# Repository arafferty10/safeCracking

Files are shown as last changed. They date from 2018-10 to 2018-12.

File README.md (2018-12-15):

# Team TAL: ATLS 4519 Safecracking Fall 2018
#### Repo for SafeCracking Class -- Using Arduino and manufactured parts to open a Sentry Safe Dial Safe

IMAGE ALT TEXT (http://www.youtube.com/watch?v=GAtKnZO2PP4 "ATLS 4519 Safe Cracking Success ")
###### Successful Opening Video

## Information

Parts List - https://docs.google.com/spreadsheets/d/1XabOUtS-7bFRwG6XeN5u8nKVINY24XkEVGik6j0RJdE/edit?usp=sharing  
3D Printed Models - https://github.com/arafferty10/safeCracking/tree/master/models

## Personal Repos
* Lou - https://github.com/lume2651/safe-cracking 
* Aidan - https://github.com/arafferty10/personalSafeCracking
* Toby - https://github.com/towu1344/Safe-Cracking

## Images
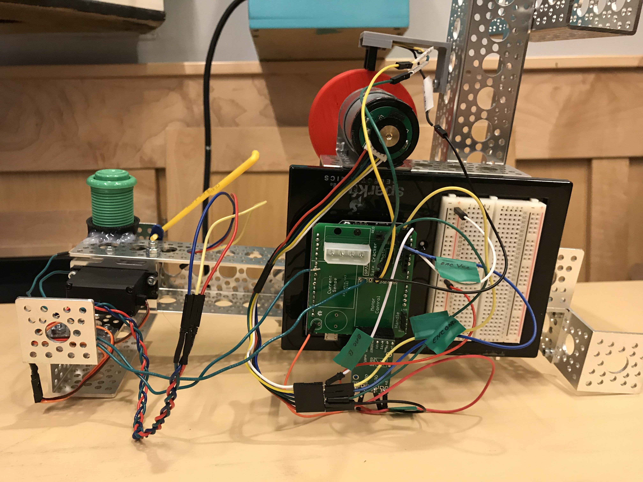
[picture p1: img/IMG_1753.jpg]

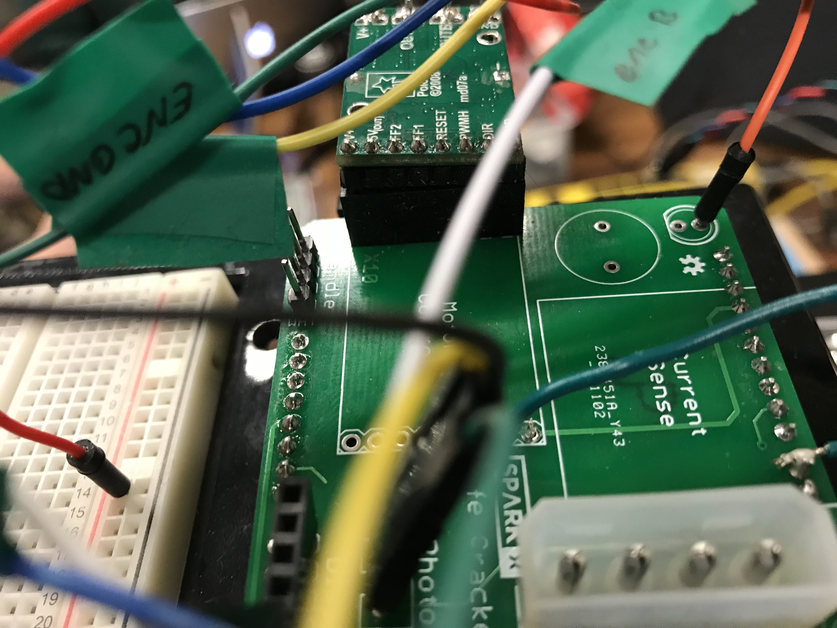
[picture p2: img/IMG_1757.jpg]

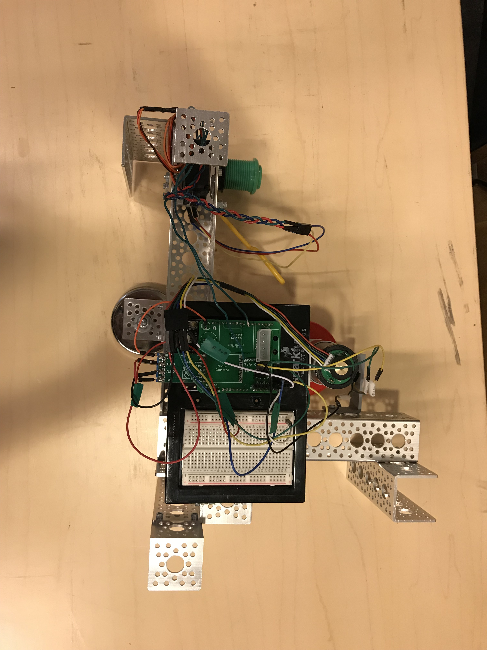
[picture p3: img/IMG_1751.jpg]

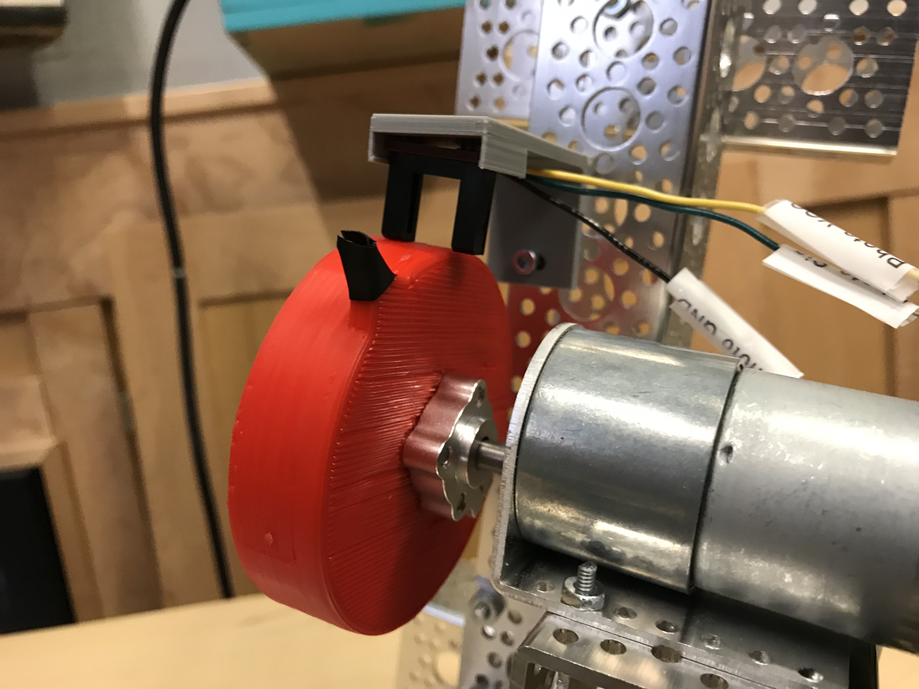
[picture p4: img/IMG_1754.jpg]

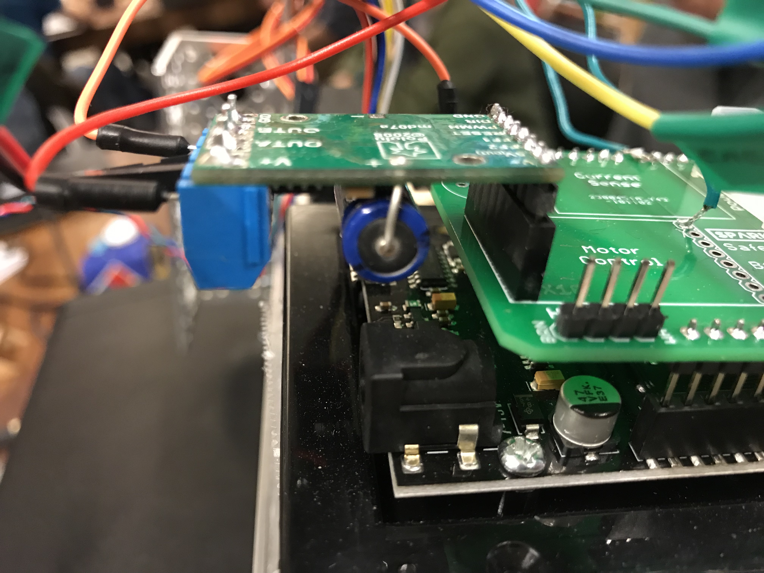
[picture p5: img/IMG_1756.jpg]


---
Video of final opening: https://github.com/arafferty10/safeCracking/blob/master/img/IMG_3121.mp4

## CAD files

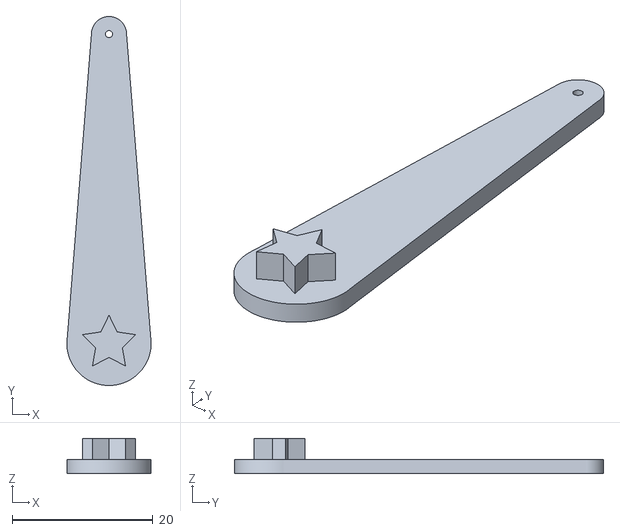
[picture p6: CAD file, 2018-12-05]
models/handlePullerArm.stl
12.0 x 52.5 x 5.00

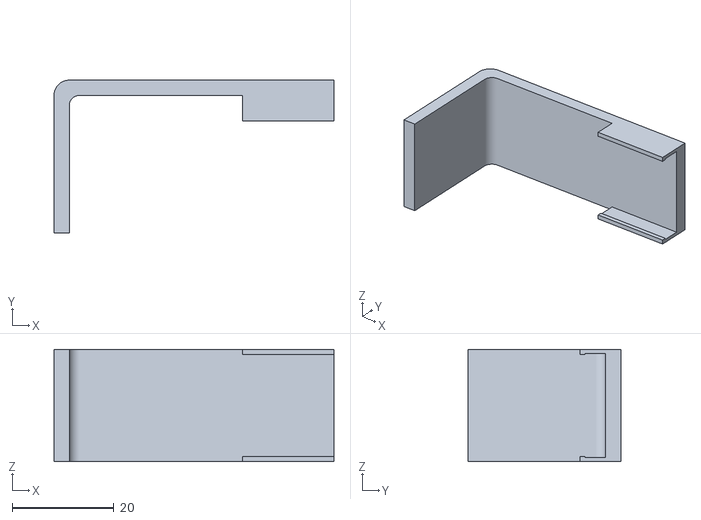
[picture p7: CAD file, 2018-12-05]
models/phoGateHolder.stl
55.0 x 30.0 x 22.0

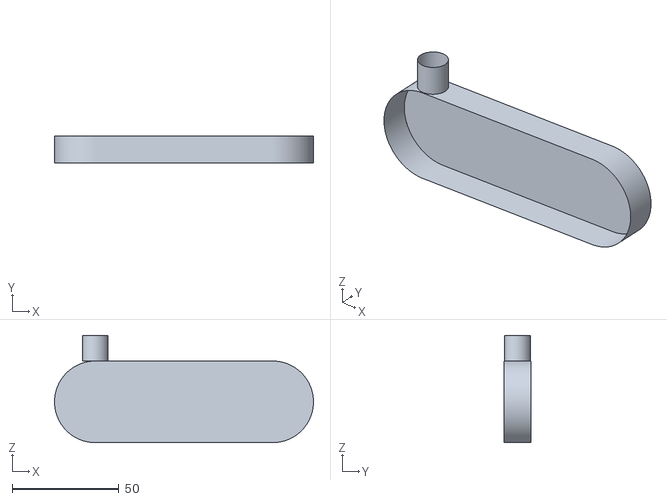
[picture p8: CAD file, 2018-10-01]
models/lou-handle-puller.stl
121.2 x 12.8 x 50.2

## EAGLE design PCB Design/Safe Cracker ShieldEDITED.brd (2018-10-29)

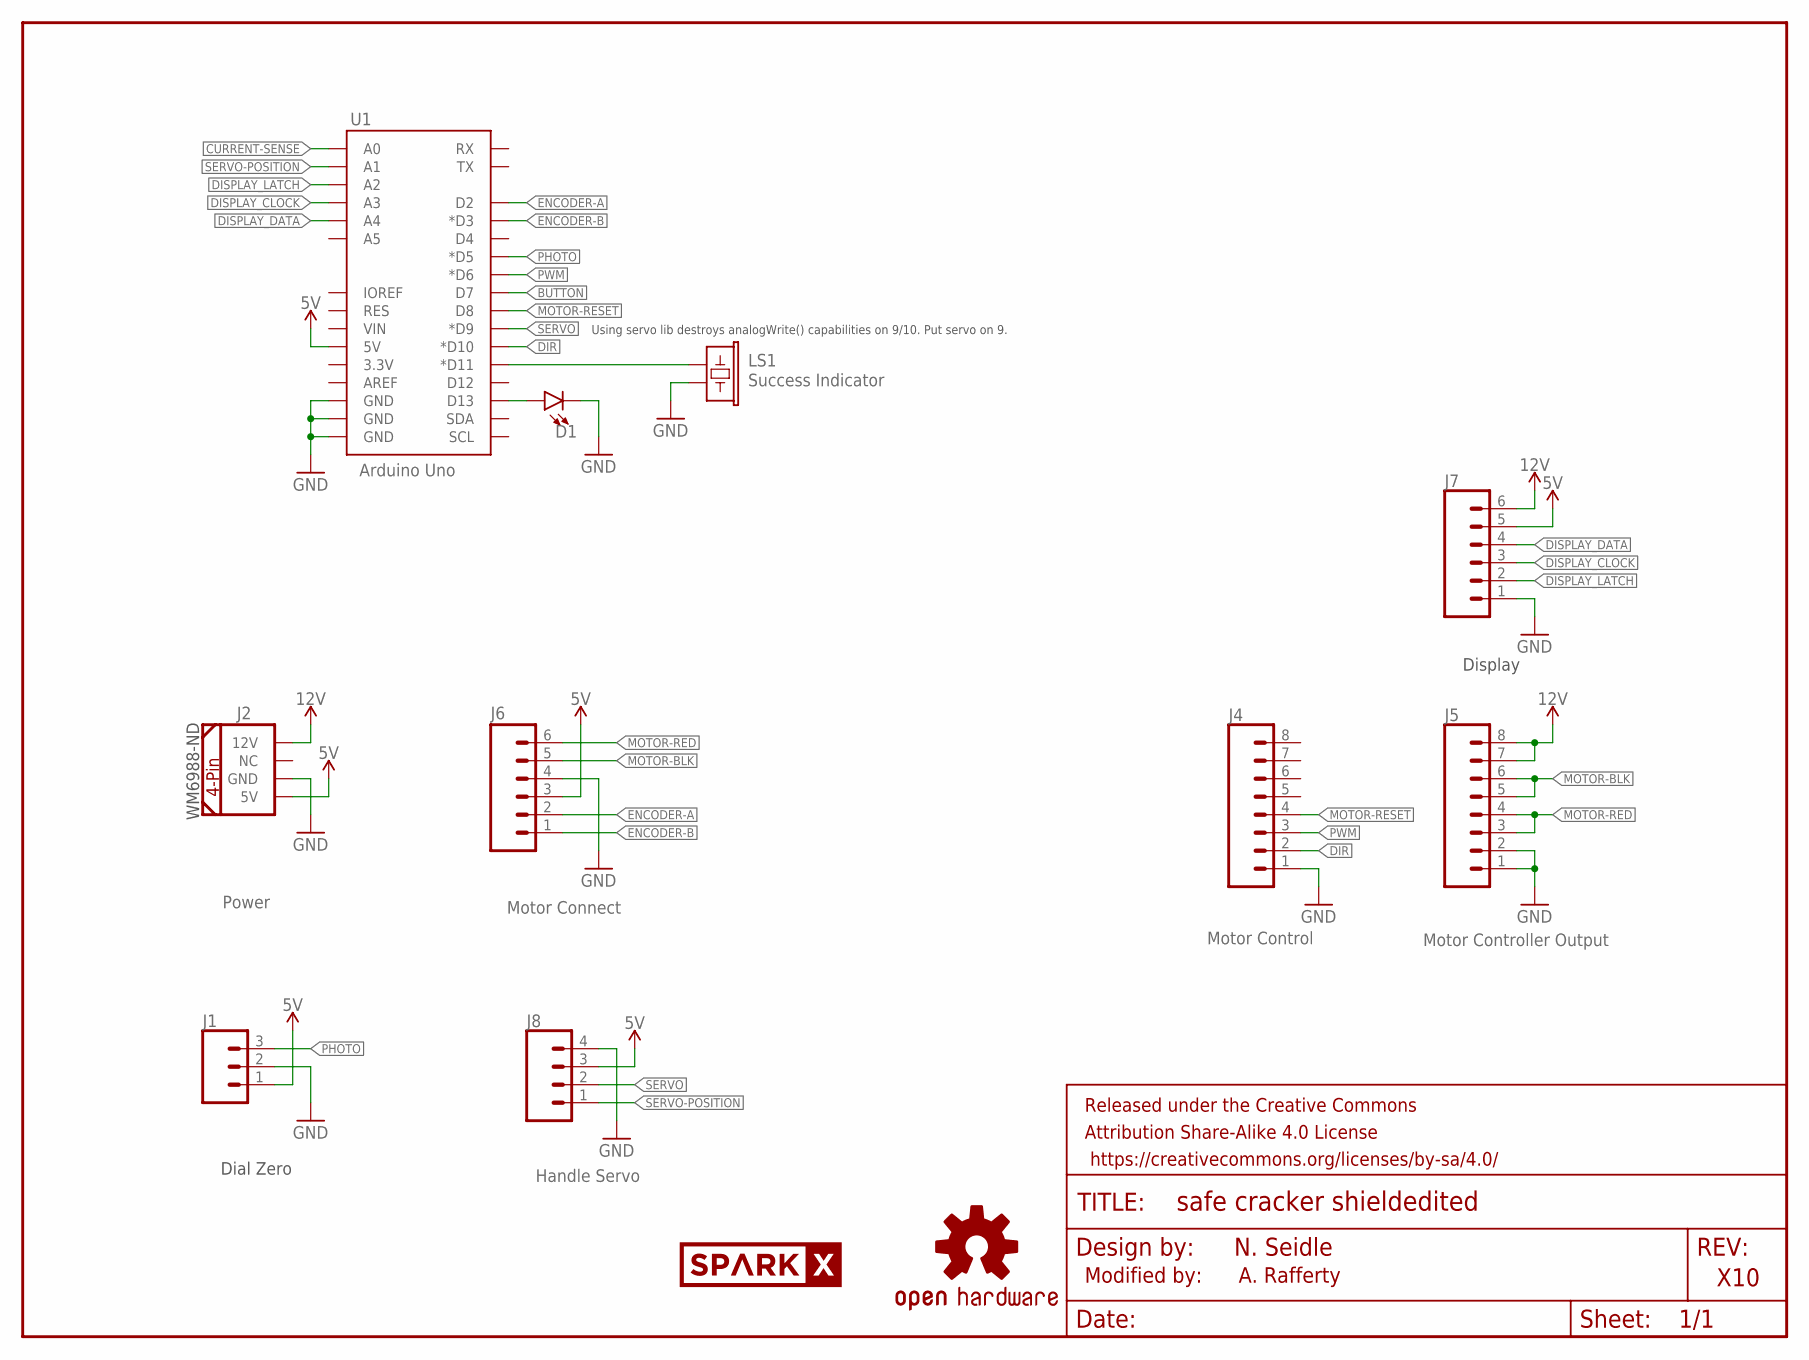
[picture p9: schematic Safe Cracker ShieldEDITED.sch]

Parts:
D1: LED5MM; LED_5MM
FRAME1: FRAME-LETTER; CREATIVE_COMMONS
J1: CONN_03JST-PTH-VERT; JST-3-PTH-VERT
J2: Power; COMPUTER-PERIPHERAL-POWER-RA
J4: Motor Control; 1X08
J5: Motor Controller Output; 1X08
J6: Motor Connect; 1X06@1
J7: CONN_06SILK_FEMALE_PTH; 1X06
J8: Handle Servo; 1X04
LOGO2: OSHW-LOGOS; OSHW-LOGO-S
LS1: Success Indicator; BUZZER-12MM
U1: Arduino Uno; UNO_R3_SHIELD_NOLABELS
U$1: SPARKX-LOGO5; SPARKX-LARGE

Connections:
5V: J1.1, J2.5V, J6.3, J7.5, J8.3, U1.5V
12V: J2.12V, J5.7, J5.8, J7.6
BUTTON: U1.D7
BUZZ: LS1.+ (1), U1.D11 (*D11)
CURRENT-SENSE: U1.A0
DIR: J4.2, U1.D10 (*D10)
DISPLAY_CLOCK: J7.3, U1.A3
DISPLAY_DATA: J7.4, U1.A4
DISPLAY_LATCH: J7.2, U1.A2
ENCODER-A: J6.2, U1.D2
ENCODER-B: J6.1, U1.D3 (*D3)
GND: D1.K (C), J1.2, J2.GND, J4.1, J5.1, J5.2, J6.4, J7.1, J8.4, LS1.- (2), U1.GND@0 (GND), U1.GND@1 (GND), U1.GND@2 (GND)
MOTOR-BLK: J5.5, J5.6, J6.5
MOTOR-RED: J5.3, J5.4, J6.6
MOTOR-RESET: J4.4, U1.D8
unnamed: D1.A, U1.D13
PHOTO: J1.3, U1.D5 (*D5)
PWM: J4.3, U1.D6 (*D6)
SERVO: J8.2, U1.D9 (*D9)
SERVO-POSITION: J8.1, U1.A1

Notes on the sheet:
WM6988-ND
N. Seidle
X10
Using servo lib destroys analogWrite() capabilities on 9/10. Put servo on 9.
Dial Zero
Display
Modified by: A. Rafferty

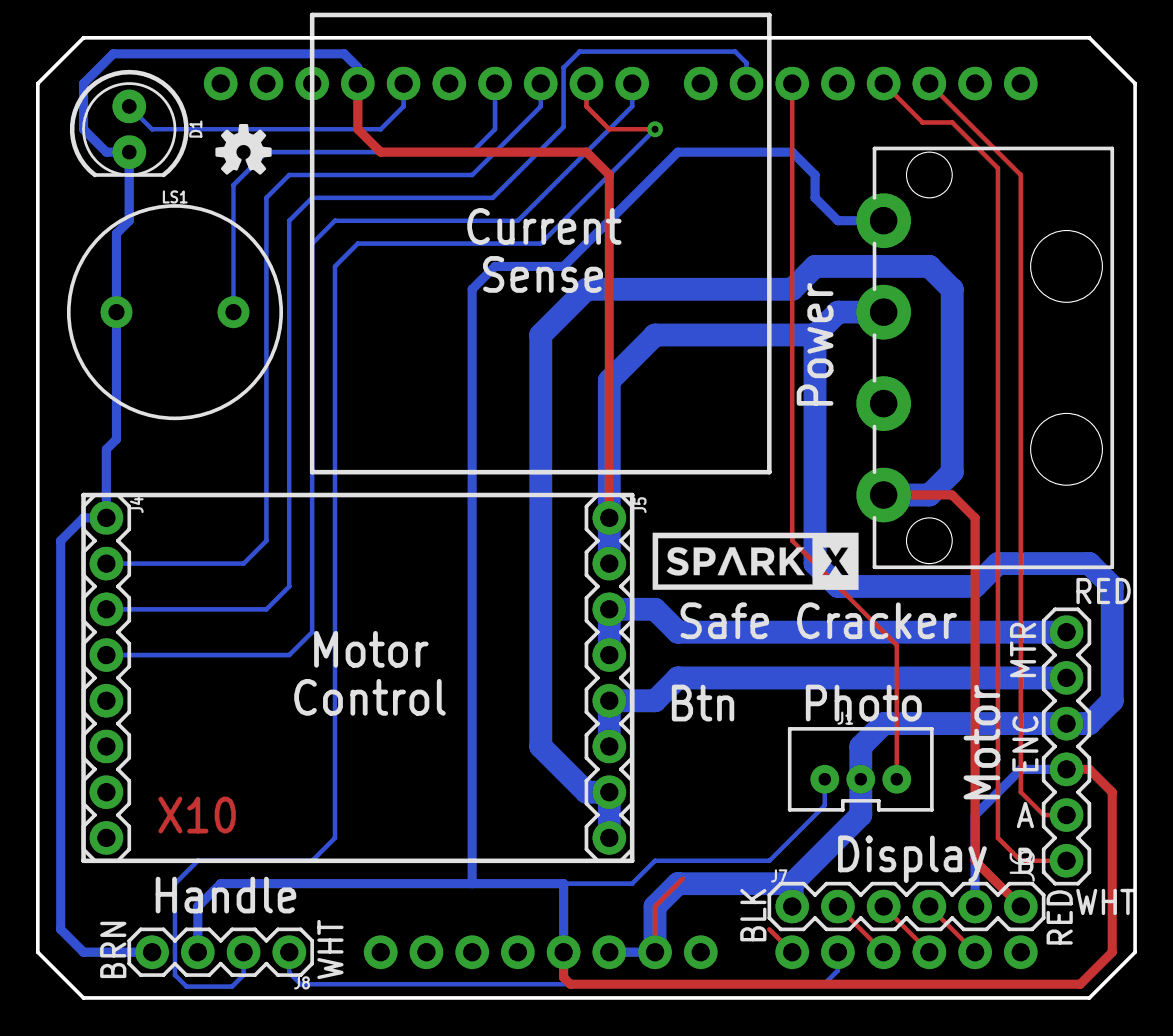
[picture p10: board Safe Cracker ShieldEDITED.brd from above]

Board: 2 copper layers, 61.0 x 53.3 mm, 13 parts (0 on the bottom side), 18 nets.

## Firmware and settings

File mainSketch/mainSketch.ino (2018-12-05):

#include <EEPROM.h>
#include <Servo.h>

#define CCW 0
#define CW 1
// EEPROM Storage Locations
const int DIAL_ROTATION_SPEED = 0;

#define LOCATION_HOME_OFFSET 0

// Pin layout
const int motorControl = 6;
const int photo = 7;
const int motorReset = 8;
const int motorDir = 3;

volatile int steps = 0;
boolean dir = CW;
boolean prevDir = CW;

byte homeOffset = 0;

const int timeMotorStop = 125;

int switchDirectionAdjustment = (84 * 0) + 0; //Use 'Test dial control' to determine adjustment size

//Rotate the dial Counter Clockwise
//-----------------------------------------------------
void rotateCCW(int _steps){
  Serial.println("inside rotateCCW()");

  digitalWrite(motorDir, LOW);

  int stepsLeft = _steps;

  while(stepsLeft > 0){
    Serial.println("trying to turn...");
    analogWrite(motorControl, 255);
    stepsLeft--;
  }
  analogWrite(motorControl, 0);
}
//-----------------------------------------------------

//Looks at current dial position and determines number of steps between where
//you are and where you want to go
//-----------------------------------------------------
int stepsRequired(int curSteps, int dest){
  if(dir == CW){
    if( curSteps >= dest) {
      return (curSteps - dest);
    } else if(curSteps < dest){
      return (8400 - dest + curSteps);
    }
  } else if(dir == CCW){
    if(curSteps >= dest){
      return (8400 - curSteps + dest);
    } else if(curSteps < dest){
      return (dest - curSteps);
    }
  }
}
//-----------------------------------------------------

//Given a step value, go to that step
//Returns the delta from what you asked and where it ended up
//Adding a full rotation will add a 360 degree full rotation
int gotoStep(int stepGoal, boolean addAFullRotation)
{
  //Coarse speed and window control how fast we arrive at the digit on the dial
  //Having too small of a window or too fast of an attack will make the dial
  //overshoot.
  int coarseSpeed = 200; //Speed at which we get to coarse window (0-255). 150, 200 works. 210, 230 fails
  int coarseWindow = 1250; //Once we are within this amount, switch to fine adjustment
  int fineSpeed = 50; //Less than 50 may not have enough torque
  int fineWindow = 32; //One we are within this amount, stop searching

  //Because we're switching directions we need to add extra steps to take
  //up the slack in the encoder
  if (dir == CW && prevDir == CCW)
  {
    steps += switchDirectionAdjustment;
    if (steps > 8400) steps -= 8400;
    prevDir = CW;
  }
  else if (dir == CCW && prevDir == CW)
  {
    steps -= switchDirectionAdjustment;
    if (steps < 0) steps += 8400;
    prevDir = CCW;
  }

  setMotorSpeed(coarseSpeed); //Go!
  while (stepsRequired(steps, stepGoal) > coarseWindow) ; //Spin until coarse window is closed

  //After we have gotten close to the first coarse window, proceed past the goal, then proceed to the goal
  if (addAFullRotation == true)
  {
    int tempStepGoal = steps + 8400/2; //Move 50 away from current position
    if (tempStepGoal > 8400) tempStepGoal -= 8400;

    //Go to temp position
    while (stepsRequired(steps, tempStepGoal) > coarseWindow) ;

    //Go to stepGoal
    while (stepsRequired(steps, stepGoal) > coarseWindow) ; //Spin until coarse window is closed
  }

  setMotorSpeed(fineSpeed); //Slowly approach

  while (stepsRequired(steps, stepGoal) > fineWindow) ; //Spin until fine window is closed

  setMotorSpeed(0); //Stop

  delay(timeMotorStop); //Wait for motor to stop

  int delta = steps - stepGoal;

  /*if (direction == CW) Serial.print("CW ");
    else Serial.print("CCW ");
    Serial.print("stepGoal: ");
    Serial.print(stepGoal);
    Serial.print(" / Final steps: ");
    Serial.print(steps);
    Serial.print(" / delta: ");
    Serial.print(delta);
    Serial.println();*/

  return (delta);
}

//-----------------------------------------------------

void enableMotor(){
  digitalWrite(motorReset, HIGH);
}

void disableMotor(){
  digitalWrite(motorReset, LOW);
}

// Sets rotation speed of dial motor
// Expects value between 0-100%
//-----------------------------------------------------
int setDialSpeed(int _rotationSpeed) {
  int rotSpeed = map(_rotationSpeed, 0, 100, 0, 255);
  EEPROM.put(rotSpeed, DIAL_ROTATION_SPEED);
  analogWrite(motorControl, rotSpeed);
  Serial.print(F("Dial speed set to: "));
  Serial.println(rotSpeed);

  return _rotationSpeed;
}
//-----------------------------------------------------

//Simple boolean to see if flag is detected
//-----------------------------------------------------
bool detectFlag(){

  if(digitalRead(photo) == LOW) {
    Serial.println("FLAG DETECTED");
    return (true);
  }
  return (false);

}
//-----------------------------------------------------

bool phoneHome(){

  // return atHome;
}

//Given a dial number, goto that value
//Returns the dial value thats ended on
//-----------------------------------------------------
int setDial(int dialValue, boolean extraSpin)
{
  //Serial.print("Want dialValue: ");
  //Serial.println(dialValue);

  int encoderValue = convertDialToEncoder(dialValue); //Get encoder value
  Serial.print("Want encoderValue: ");
  Serial.println(encoderValue);

  gotoStep(encoderValue, extraSpin); //Goto that encoder value
  Serial.print("After movement, steps: ");
  Serial.println(steps);

  int actualDialValue = convertEncoderToDial(steps); //Convert back to dial values
  Serial.print("After movement, dialvalue: ");
  Serial.println(actualDialValue);

  return (actualDialValue);
}

//-----------------------------------------------------

void setMotorSpeed(int speedValue)
{
  analogWrite(motorControl, speedValue);
}

//-----------------------------------------------------

//Given an encoder value, tell me where on the dial that equates
//Returns 0 to 99
//If there are 100 numbers on the dial, each number is 84 ticks wide
//-----------------------------------------------------
int convertEncoderToDial(int encoderValue)
{
  int dialValue = encoderValue / 84; //2388/84 = 28.43
  int partial = encoderValue % 84; //2388%84 = 36

  if (partial >= (84 / 2)) dialValue++; //36 < 42, so 28 is our final answer

  if (dialValue > 99) dialValue -= 100;

  return (dialValue);
}

//-----------------------------------------------------


//Given a dial value, covert to an encoder value (0 to 8400)
//If there are 100 numbers on the dial, each number is 84 ticks wide
//-----------------------------------------------------
int convertDialToEncoder(int dialValue)
{
  int encoderValue = dialValue * 84;

  if (encoderValue > 8400)
  {
    Serial.print("Whoa! Your trying to go to a dial value that is illegal. encoderValue: ");
    Serial.println(encoderValue);
    while (1);
  }

  return (84 * dialValue);
}

//-----------------------------------------------------

void setup() {

  pinMode(photo, INPUT_PULLUP);
  pinMode(motorDir, OUTPUT);
  pinMode(motorControl, OUTPUT);    //motorPWM
  pinMode(motorReset, OUTPUT);

  enableMotor();
  Serial.begin(115200);
  Serial.println();
  Serial.println("Safe Cracker");

  //Load settings from EEPROM
   homeOffset = EEPROM.read(LOCATION_HOME_OFFSET);

}

//-----------------------------------------------------
void loop() {

  char incoming;

  // Print text menu
  Serial.println();
  Serial.println("Main Menu");
  Serial.println(F("1. Rotate motor"));
  Serial.println(F("2. Detech Flag"));
  Serial.println(F("3. Set Starting Dial Value/Go Home"));
  Serial.println(F("4. placeholder option"));
  Serial.println(F("5. placeholder option"));
  Serial.println(F("6. Start Cracking!"));
  Serial.println();
  Serial.println(F("Enter your choice"));

  while(!Serial.available());


  incoming = Serial.read();

  // while(!Serial.available()){
    if(incoming == '1')
    {
      Serial.println("Case 1!");
      Serial.print("Rotating...");
      rotateCCW(1000);
    }
    else if(incoming == '2')
    {
      detectFlag();
      Serial.println("Case 2!");
    }
    //-----------------------------------------------------
    else if(incoming == '3')
    {
      Serial.println("Case 3!");
      //Go to starting conditions
      detectFlag(); //Detect the flag and center the dial based on it

      Serial.print(F("Offset from home is: "));
      Serial.println(homeOffset);

      int zeroLocation = 0;

      while (1) //Error checking
      {
        Serial.print(F("Enter where dial is actually at: "));

        while (!Serial.available()); //Wait for user input

        Serial.setTimeout(1000);
        zeroLocation = Serial.parseInt(); //Read user input

        Serial.print(zeroLocation);

        //Check to make sure the user input is in bounds
        if (zeroLocation >= 0 && zeroLocation <= 99) break;
        Serial.println(F(" out of bounds"));
      }

      homeOffset = zeroLocation;

      Serial.print(F("\n\rSetting home offset to: "));
      Serial.println(homeOffset);

      EEPROM.write(LOCATION_HOME_OFFSET, homeOffset);

      //Adjust steps with the real-world offset
      steps = (84 * homeOffset); //84 * the number the dial sits on when 'home'

      setDial(0, false); //Turn to zero

      Serial.println(F("Dial should be at: 0"));

    }
    //-----------------------------------------------------
    else if(incoming == '4')
    {
      Serial.println("Case 4!");
    }
    else
    {
      Serial.print("Unknown Option: ");
      Serial.println(incoming, HEX);
    }

  // }

  // while(!Serial.available()){
  //
  //   while(Serial.available());
  //   incoming = Serial.read();
  //   Serial.print("Incoming serial: ");
  //   Serial.println(incoming);
  //
  // }

}

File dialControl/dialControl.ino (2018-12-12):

#include <EEPROM.h>
#include <Servo.h>
#include "eeprom_loc.h"

Servo handle;

#define CCW 0
#define CW 1

// Pin definitions
const int motorControl = 6; // motor PWM
const int photoGate = 5;
const int motorReset = 8; // motor reset pin
const int motorDir = 10; // motor direction | HIGH - CW, LOW - CCW
const int encA = 2;
const int encB = 3;
const int servoPin = 9;

int testSpots[] = {99, 8, 16, 24, 33, 41, 50, 58, 66, 74, 83, 91}; 
boolean indentsToTry[12];
int indentWidths[12];
int indentLocations[12];


volatile int steps = 0;

boolean dir = CW; // default direction (also direction for first digit of combo)
boolean prevDir = CW;
int homeOffset = 0; // Found running findFlag()

int switchDirAdjustment = (84 * 0) + 0;

const int timeMotorStop = 125; // ms for motor to stop spinning after stop command

int servoRestingPosition = 0; // handle, at rest position
int servoTryPosition = 50; // position when measuring
int servoHighPressurePosition = 60; // position when opening safe

const int timeServoApply = 350;
const int timeServoRelease = 250;

void setup() {
  // put your setup code here, to run once:
  pinMode(photoGate, INPUT);
  pinMode(motorDir, OUTPUT);
  pinMode(motorControl, OUTPUT);
  pinMode(motorReset, OUTPUT);
//  handle.attach(servoPin);
//  handle.write(0);
  motorOn();
  Serial.begin(115200);
  Serial.println();
  Serial.println("Safe Cracker");

  attachInterrupt(digitalPinToInterrupt(encA), countA, CHANGE);
  attachInterrupt(digitalPinToInterrupt(encB), countB, CHANGE);

  // Load settings from EEPROM
  EEPROM.get(LOCATION_HOME_OFFSET, homeOffset); // read in homeOffset
  Serial.print("Home offset: ");
  Serial.println(homeOffset);

  // Init dial -> find home, set offset, go to zero
//  findFlag();
//  steps = (84 * homeOffset);
//  setDial(0, false);
  
}

void loop() {

  char incoming;

  // Print text menu
  Serial.println();
  Serial.println("Main Menu");
  Serial.println(F("1. Go home | Reset Dial"));
  Serial.println(F("2. Go to specific dial number"));
  Serial.println(F("3. Dial position testing"));
  Serial.println(F("4. Measure indents"));
  Serial.println(F("5. Position Testing"));
  Serial.println(F("6. Display Indent Center Values"));
  Serial.println(F("7. Test servo"));
  Serial.println();
  Serial.println(F("Enter your choice"));

  while(!Serial.available());


  incoming = Serial.read();

  // while(!Serial.available()){
    if(incoming == '1')
    {
      findFlag();
      Serial.print("Home offset: ");
      Serial.println(homeOffset);

      int zeroLocation = 0;

      while(1){
        Serial.print("Enter where dial is actually at: ");

        while(!Serial.available());

        Serial.setTimeout(1500);
        zeroLocation = Serial.parseInt();

        Serial.print(zeroLocation);
        if(zeroLocation >= 0 && zeroLocation <= 99) break;
        Serial.println(" out of bounds");
      }
      
      homeOffset = zeroLocation;
      Serial.print("\nSetting home offset to: ");
      Serial.println(homeOffset);

      EEPROM.write(LOCATION_HOME_OFFSET, homeOffset);
      
      steps = (84 * homeOffset);

      setDial(10,false);
      
      Serial.println("Dial should be at: 10");

    }
    else if(incoming == '2')
    {
      Serial.println("Enter a dial number ");
      Serial.setTimeout(2000);
      int reqPos = Serial.parseInt();

      Serial.print("Going to dial position: ");
      Serial.println(reqPos);

      setDial(reqPos,false);
    }
    //-----------------------------------------------------
    else if(incoming == '3')
    {
      Serial.println("Dial positioning test");
      positionTesting(); // will pick random locations on the dial and see if we can go to them

    }
    //-----------------------------------------------------
    else if(incoming == '4')
    {
      Serial.println("Measure Indents");
      int measurements = 0;

      while(1){ // waiting for good input
        Serial.print("How many measurements would you like to take? ");
        while(!Serial.available());
        Serial.setTimeout(1000);
        measurements = Serial.parseInt();

        if(measurements >= 1 && measurements <= 20) break;

        Serial.print(measurements);
        Serial.println(" out of bounds");
      }
      Serial.println(measurements);
      measureDiscC(measurements);
    }
    else if(incoming == '5')
    {
      Serial.println("Case 5!");
      
    } else if(incoming == '6'){
      
    } else if(incoming == '7'){
      testServo();
    } else {
      Serial.print("Unknown Option: ");
      Serial.println(incoming, HEX);
    }

}

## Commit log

2018-10-01 Add handle puller model
    [lou-handle-puller.stl]
2018-10-01 Aidan Handle Design
    [AidanSafeHandle.f3d]
2018-10-01 Toby Wu Handle Puller
    [handlePuller.3dm]
2018-10-01 Toby Wu Control Motor
2018-10-09 personal git added
    [AidanSafeHandle.f3d]
2018-10-10 add EEPROM and Pin sections
2018-10-10 add motor control functions
2018-10-17 add encoderTest sketch folder
2018-10-17 test sketch for reading in encoder values
2018-10-29 PCB Designs
    [Safe Cracker ShieldEDITED.brd, Safe Cracker ShieldEDITED.sch]
2018-10-31 servo header, changed serial rate
2018-11-26 add basic motor control functions (on, off, turn CW/CCW) and function for detecting photogate
2018-11-26 add dial <-> encoder conversion functions
2018-11-26 add encoder count functions
2018-12-15 Revert "add photos"
    This reverts commit d224561b4f8bf672d165ef35202d130146be8ae8.
    [dialControl.ino]

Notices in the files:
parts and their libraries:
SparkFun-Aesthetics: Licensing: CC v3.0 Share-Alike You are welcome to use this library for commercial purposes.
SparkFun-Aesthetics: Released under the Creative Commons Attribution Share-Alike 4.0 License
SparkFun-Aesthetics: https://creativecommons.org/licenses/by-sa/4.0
